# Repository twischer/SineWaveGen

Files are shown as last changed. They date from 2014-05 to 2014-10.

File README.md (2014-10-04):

SineWaveGen
===========

Messungen
===========

Gemessen wurde der benötigte Strom für die 12V-Versorgung

Bei Verwendung des Sinus-Generators
Ohne Zwischenkreisspannung:		10,6 mA
Mit Zwischenkreisspannung:		8 mA

Bei Verwendung des Trapez-Generators
Ohne Zwischenkreisspannung:		11,3 mA
Mit Zwischenkreisspannung:		7,5 mA

Leistungsaufnahme mit 99W (0,42A) Glühlampe
Trapez-Generator:				120W (0,51A)

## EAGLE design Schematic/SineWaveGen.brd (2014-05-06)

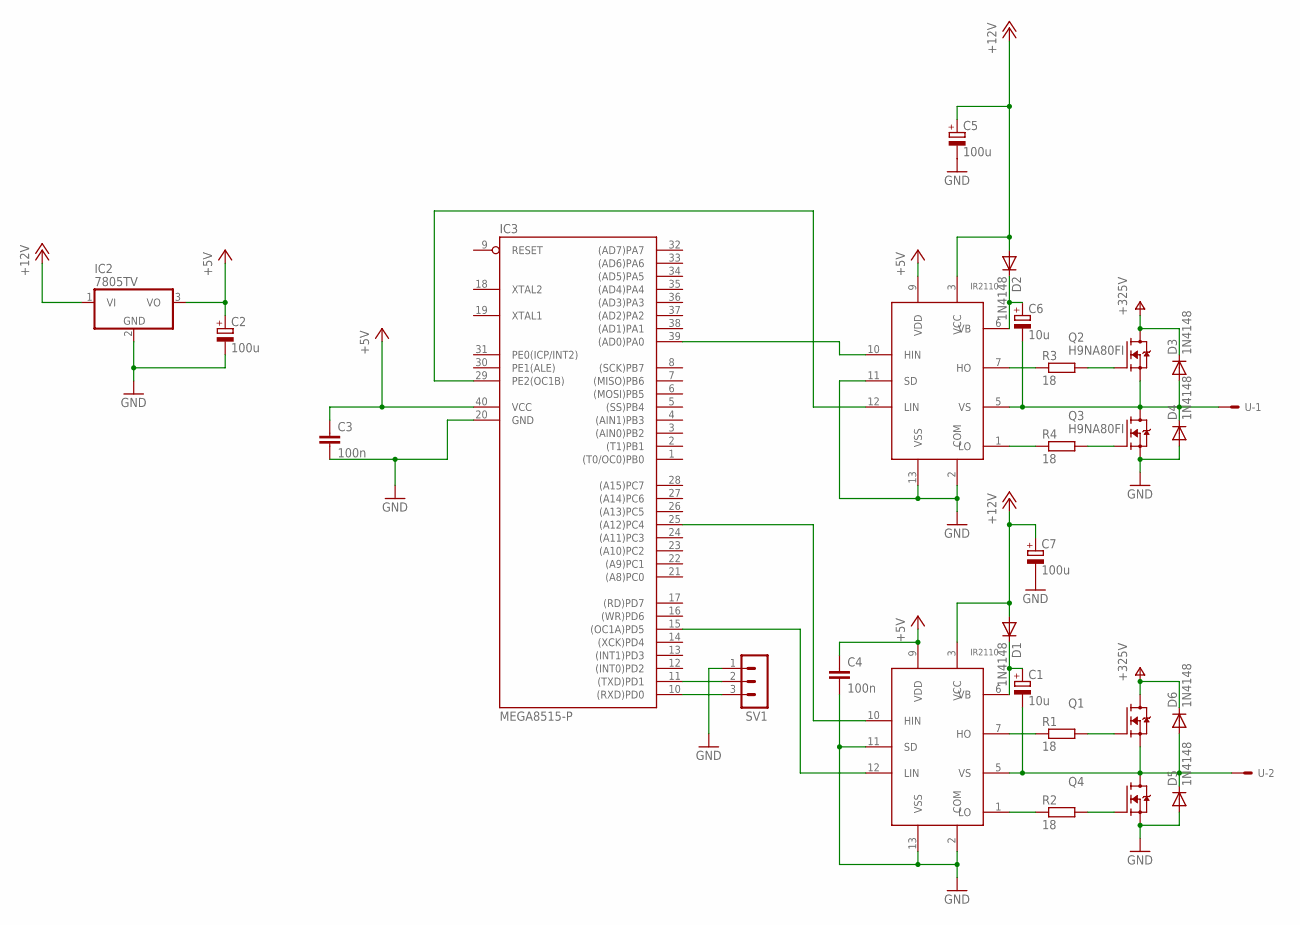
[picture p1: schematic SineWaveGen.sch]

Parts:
C1, C6: 10u; E2,5-7
C2, C5, C7: 100u; E2,5-7
C3, C4: 100n; C050-035X075
D1, D2, D3, D4, D5, D6: 1N4148; DO35-7
IC2: 7805TV; TO220V
IC3: MEGA8515-P; DIL40
Q1, Q4: SPW47N60S5; P-TO247
Q2, Q3: H9NA80FI; P-TO247
R1, R2, R3, R4: 18; 0207/12
SV1: MA03-1
U: 5566-2
U$1, U$2: IR2110; DIL14

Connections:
+5V: C2.+, C3.1, C4.1, IC2.3 (VO), IC3.40 (VCC), U$1.9 (VDD), U$2.9 (VDD)
+12V: C5.+, C7.+, D1.A, D2.A, IC2.1 (VI), U$1.3 (VCC), U$2.3 (VCC)
GND: C2.-, C3.2, C4.2, C5.-, C7.-, D4.A, D5.A, IC2.2 (GND), IC3.20 (GND), Q3.3 (S), Q4.3 (S), SV1.1, U$1.2 (COM), U$1.11 (SD), U$1.13 (VSS), U$2.2 (COM), U$2.11 (SD), U$2.13 (VSS)
unnamed: Q1.1 (G), R1.2
unnamed: IC3.39 ((AD0)PA0), U$2.10 (HIN)
unnamed: IC3.15 ((OC1A)PD5), U$1.12 (LIN)
unnamed: IC3.25 ((A12)PC4), U$1.10 (HIN)
unnamed: R2.1, U$1.1 (LO)
unnamed: C1.-, D5.C, D6.A, Q1.3 (S), Q4.2 (D), U.2, U$1.5 (VS)
unnamed: C1.+, D1.C, U$1.6 (VB)
unnamed: Q4.1 (G), R2.2
unnamed: R1.1, U$1.7 (HO)
unnamed: IC3.11 ((TXD)PD1), SV1.2
unnamed: IC3.10 ((RXD)PD0), SV1.3
unnamed: IC3.29 (PE2(OC1B)), U$2.12 (LIN)
unnamed: R3.1, U$2.7 (HO)
unnamed: Q2.1 (G), R3.2
unnamed: R4.1, U$2.1 (LO)
unnamed: Q3.1 (G), R4.2
unnamed: C6.-, D3.A, D4.C, Q2.3 (S), Q3.2 (D), U.1, U$2.5 (VS)
unnamed: C6.+, D2.C, U$2.6 (VB)
V+: D3.C, D6.C, Q1.2 (D), Q2.2 (D)

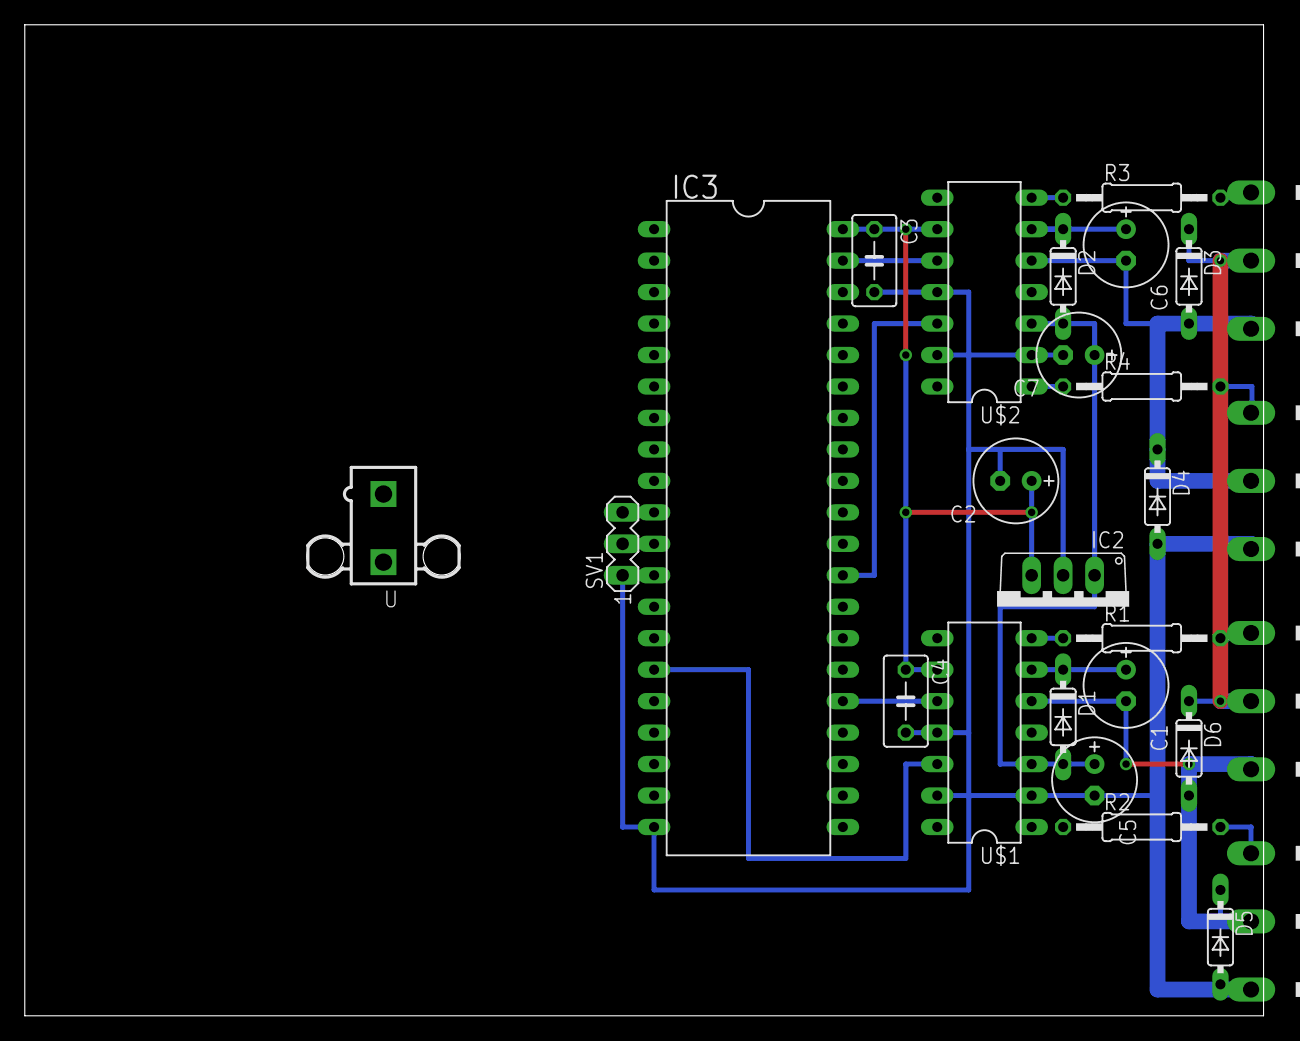
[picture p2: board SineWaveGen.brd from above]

Board: 2 copper layers, 100.0 x 80.0 mm, 27 parts (0 on the bottom side), 22 nets.

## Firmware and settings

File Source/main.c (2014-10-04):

#include <stdint.h>
#include <stdbool.h>

#include <avr/io.h>
#include <avr/interrupt.h>
#include <avr/wdt.h>

#include <util/delay.h>


#define BRIDGE1_HIGH_DDR		DDRA
#define BRIDGE1_HIGH_PORT		PORTA
#define BRIDGE1_HIGH_IN			PINA
#define BRIDGE1_HIGH_PIN		PA0

#define BRIDGE1_LOW_DDR			DDRE
#define BRIDGE1_LOW_PORT		PORTE
#define BRIDGE1_LOW_IN			PINE
#define BRIDGE1_LOW_PIN			PE2
#define BRIDGE1_LOW_OCR			OCR1BL


#define BRIDGE2_HIGH_DDR		DDRC
#define BRIDGE2_HIGH_PORT		PORTC
#define BRIDGE2_HIGH_IN			PINC
#define BRIDGE2_HIGH_PIN		PC4

#define BRIDGE2_LOW_DDR			DDRD
#define BRIDGE2_LOW_PORT		PORTD
#define BRIDGE2_LOW_IN			PIND
#define BRIDGE2_LOW_PIN			PD5
#define BRIDGE2_LOW_OCR			OCR1AL


#define OUTPUT_SWITCH_PORT		PORTD
#define OUTPUT_SWITCH_IN		PIND
#define OUTPUT_SWITCH_PIN		PD7




// The time out between a half bridge (in µs)
#define FET_TIMEOUT				3
// length of the v+ and v+ pulse (in ms)
#define PULSE_TIME				7
// length of the null pulse where both outputs are connected to gnd (in ms)
#define NULL_TIME				3



const uint8_t SINE_TABLE[] =  { 0, 21,41,61,81,100,119,136,153,169,184,198,210,221,230,238,245,250,253,255,253,250,245,238,230,221,210,198,184,169,153,136,119,100,81,61,41,21, 0 };


ISR(TIMER1_OVF_vect)
{
	static uint8_t sineTableIndex = 0;
	sineTableIndex++;
	
	static bool positiveHalfWave = true;
	
	if (sineTableIndex >= sizeof(SINE_TABLE))
	{
		positiveHalfWave = !positiveHalfWave;
		sineTableIndex = 0;
		
		// the deadband on each half bridge is given by the switch of in the sien table
		// (the 0 at the end)
		if (positiveHalfWave)
		{
			BRIDGE2_HIGH_PORT &= ~(1<<BRIDGE2_HIGH_PIN);
			BRIDGE1_HIGH_PORT |= (1<<BRIDGE1_HIGH_PIN);
		}
		else
		{
			BRIDGE1_HIGH_PORT &= ~(1<<BRIDGE1_HIGH_PIN);
			BRIDGE2_HIGH_PORT |= (1<<BRIDGE2_HIGH_PIN);
		}
	}
	
	if (positiveHalfWave)
	{
		BRIDGE2_LOW_OCR = SINE_TABLE[sineTableIndex];
		BRIDGE1_LOW_OCR = 0x00;
	}
	else
	{
		BRIDGE2_LOW_OCR = 0x00;
		BRIDGE1_LOW_OCR = SINE_TABLE[sineTableIndex];
	}
}


void switchOutputsOff(void)
{
	// open fets which are conected to v+
	BRIDGE1_HIGH_PORT &= ~(1<<BRIDGE1_HIGH_PIN);
	BRIDGE2_HIGH_PORT &= ~(1<<BRIDGE2_HIGH_PIN);
	
	// clear pwm outputs (open fets which are connected to gnd
	BRIDGE1_LOW_PORT &= ~(1<<BRIDGE1_LOW_PIN);
	BRIDGE2_LOW_PORT &= ~(1<<BRIDGE2_LOW_PIN);
	
	// disable timer and pwm to get control with the port registers to the output pins
	TCCR1A = 0x00;
	TCCR1B = 0x00;
}


void enterSafeMode(void)
{
	switchOutputsOff();
	
	// switch off watchdog to realy wait for reset
	wdt_disable();
	
	// wait for reset
	while (true)
	{
	}
}


void checkOutputConflicts(void)
{
	// switch all outputs off and wait for an avr reset
	// if both outputs of the same half bridge are active at the same time
	const uint8_t bridge1HighOut = BRIDGE1_HIGH_IN;
	const uint8_t bridge1LowOut = BRIDGE1_LOW_IN;
	if (  (bridge1HighOut & (1<<BRIDGE1_HIGH_PIN)) && (bridge1LowOut & (1<<BRIDGE1_LOW_PIN))  )
		enterSafeMode();
	
	const uint8_t bridge2HighOut = BRIDGE2_HIGH_IN;
	const uint8_t bridge2LowOut = BRIDGE2_LOW_IN;
	if (  (bridge2HighOut & (1<<BRIDGE2_HIGH_PIN)) && (bridge2LowOut & (1<<BRIDGE2_LOW_PIN))  )
		enterSafeMode();
	
	// reset watchdog timer
	wdt_reset();
}


void sineGenerator(void)
{
	// configure timer and pwm for sine wave output
	BRIDGE2_LOW_OCR = 0x00;
	BRIDGE1_LOW_OCR = 0x00;
	TCCR1A = (1<<COM1A1) | (1<<COM1B1) | (1<<WGM10);  // Clear on compare and phase correct 8-bit pwm
	TCCR1B = (0<<CS12) | (0<<CS11) | (1<<CS10);     //PRE 1
	TIMSK  = (1<<TOIE1); // enable overflow interrupt
	
	sei();
	
	DDRB = 0xFF;
	
	while(true)
	{
		checkOutputConflicts();
	}
}


void trapezeGenerator(void)
{	
	// otherwise generate a trapez
	// useful to minimize the switching time of the fets (more efficient)
	//				1	2	
	// 		NULL	-	-	!PC4	PD5
	// 		POS		+	-	!PE2	PA0
	// 		NULL	-	-	!PA0	PE2
	//		NEG		-	+	!PD5	PC4
	while (true)
	{
		// 	NULL	-	-	!PC4	PD5
		BRIDGE2_HIGH_PORT &= ~(1<<BRIDGE2_HIGH_PIN);
		_delay_us(FET_TIMEOUT);
		BRIDGE2_LOW_PORT |= (1<<BRIDGE2_LOW_PIN);		// Positiv half wave PWM
		
		checkOutputConflicts();
		_delay_ms(NULL_TIME);
		checkOutputConflicts();
		
		
		// 	POS		+	-	!PE2	PA0
		BRIDGE1_LOW_PORT &= ~(1<<BRIDGE1_LOW_PIN);		// Negativ half wave PWM
		_delay_us(FET_TIMEOUT);
		BRIDGE1_HIGH_PORT |= (1<<BRIDGE1_HIGH_PIN);
		
		checkOutputConflicts();
		_delay_ms(PULSE_TIME);
		checkOutputConflicts();
		
		
		// 	NULL	-	-	!PA0	PE2
		BRIDGE1_HIGH_PORT &= ~(1<<BRIDGE1_HIGH_PIN);
		_delay_us(FET_TIMEOUT);
		BRIDGE1_LOW_PORT |= (1<<BRIDGE1_LOW_PIN);		// Negativ half wave PWM
		
		checkOutputConflicts();
		_delay_ms(NULL_TIME);
		checkOutputConflicts();
		
		
		//		NEG		-	+	!PD5	PC4
		BRIDGE2_LOW_PORT &= ~(1<<BRIDGE2_LOW_PIN);		// Positiv half wave PWM
		_delay_us(FET_TIMEOUT);
		BRIDGE2_HIGH_PORT |= (1<<BRIDGE2_HIGH_PIN);
		
		checkOutputConflicts();
		_delay_ms(PULSE_TIME);
		checkOutputConflicts();
	}
}


int main(void)
{
	switchOutputsOff();
	
	// enable pull up for output switch input
	OUTPUT_SWITCH_PORT |= (1<<OUTPUT_SWITCH_PIN);
	
	BRIDGE1_HIGH_DDR |= (1<<BRIDGE1_HIGH_PIN);
	BRIDGE2_HIGH_DDR |= (1<<BRIDGE2_HIGH_PIN);
	
	// enable PWM outputs
	DDRD |= (1<<PD5);		// Higher half wave PWM
	DDRE |= (1<<PE2);		// Lower half wave PWM
	
	// enable watchdog timer
	wdt_enable(WDTO_15MS);
	
	
	// read output configuration from an jumper or switch
	const bool generateSineOutput = (OUTPUT_SWITCH_IN & (1<<OUTPUT_SWITCH_PIN));
	if (generateSineOutput)
		sineGenerator();
	else
		trapezeGenerator();
	
	return 0;
}

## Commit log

2014-03-25 Add inital sine wave generator (creates 50Hz signal)
    [SineTable.ods]
2014-03-25 Add schematic for power switches
    [SineWaveGen.brd, SineWaveGen.sch]
2014-04-06 use bigger distances for high voltages
    [SineWaveGen.brd, SineWaveGen.sch]
2014-05-06 Make it possible to choose a trapez generator
    [SineWaveGen.brd, SineWaveGen.sch]
2014-05-07 Enter safe mode if high and low side of the same bridge is enabled Use watchdog timer to garent this checks
